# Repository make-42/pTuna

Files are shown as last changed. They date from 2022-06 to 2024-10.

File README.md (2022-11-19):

# pTuna

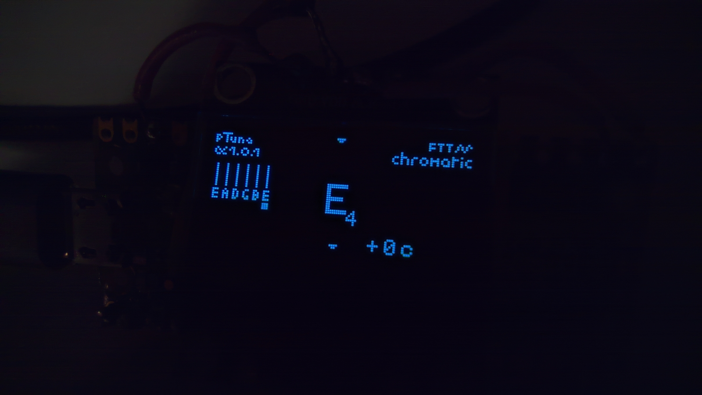
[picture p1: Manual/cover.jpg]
pTuna


An open-source DIY guitar tuner.

## Changelog

```
 - Alpha 1.0.9:
    - New splash screen
    - New boot animation
    - Slightly better code performance
    - Overclocked processor from 125MHz to 150MHz.
    - Version bump: v1.0.1 -> v1.0.9
```

## BOM (Prices in France as of June 2022)

- Raspberry Pi Pico (€ 4)
- SSD1306 OLED Display (€ 1.73)
- Adafruit PDM MEMS Microphone Breakout (Product ID: 3492) (€ 4.62)
- CR2032 (Battery holder) (€ 0.50)
- Toggle switch (€ 0.50)
- Wires (€ 0.40)

Total: € 11.75 (excluding shipping)

Note: If you are in Paris I'd definitely recommend [letmeknow](https://letmeknow.fr) for getting parts. The prices are affordable and the staff lovely!

## Building firmware

- Clone this repo
- Run this command:

`cd ./pTuna/Firmware/final/`

- Edit `build.sh` to point to your pico SDK folder.

- Build with:

`sh build.sh`

## Wiring

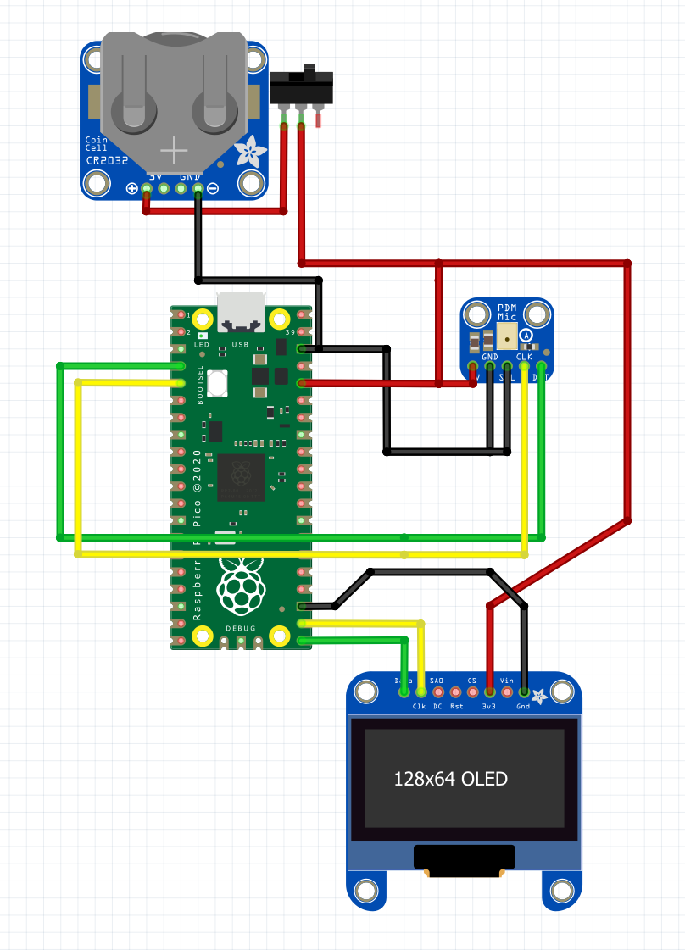
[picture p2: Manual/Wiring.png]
pTuna Wiring


## Schematic

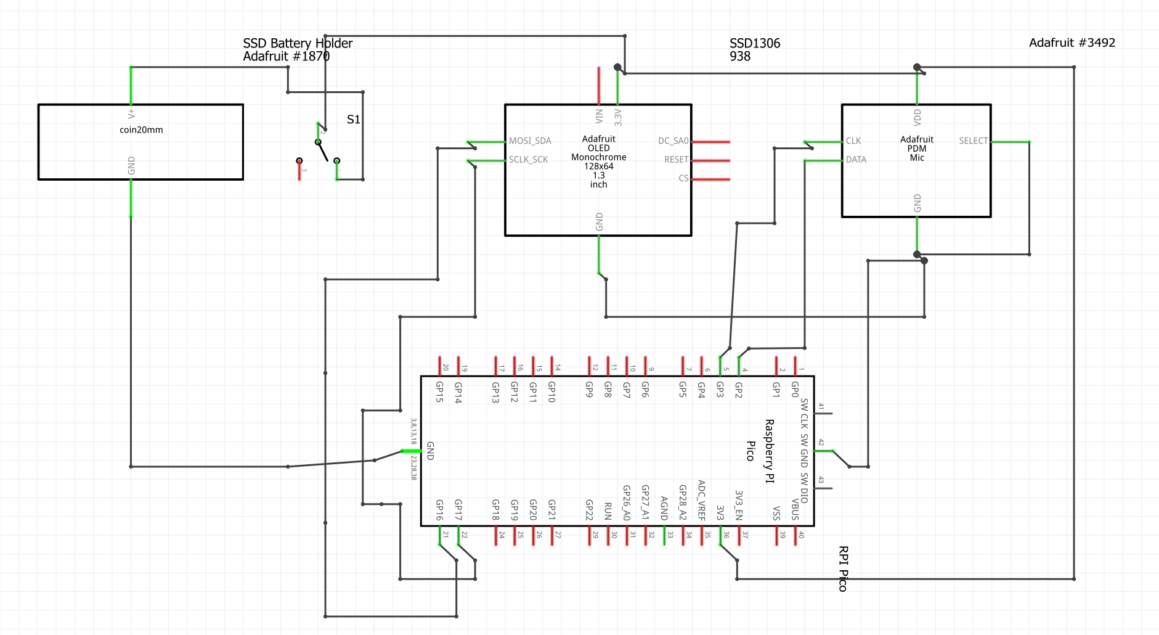
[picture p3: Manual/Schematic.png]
pTuna Schematic


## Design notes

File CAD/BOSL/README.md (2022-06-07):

# BOSL
The Belfry OpenScad Library - A library of tools, shapes, and helpers to make OpenScad easier to use.

This library is a set of useful tools, shapes and manipulators that I developed while working on various
projects, including large ones like the Snappy-Reprap printed 3D printer.

## Installation
1. Download the .zip or .tar.gz release file for this library.
2. Unpack it.  It should create a `BOSL-v1.0` directory with the library files within it.
3. Rename the directory to `BOSL`.
4. Move the `BOSL` directory into the apropriate OpenSCAD library directory for your platform:
    - Windows: `My Documents\OpenSCAD\libraries\`
    - Linux: `$HOME/.local/share/OpenSCAD/libraries/`
    - Mac OS X: `$HOME/Documents/OpenSCAD/libraries/`
5. Restart OpenSCAD.

## Terminology
For purposes of the BOSL library, the following terms apply:
- **Left**: Towards X-
- **Right**: Towards X+
- **Front**/**Forward**: Towards Y-
- **Back**/**Behind**: Towards Y+
- **Bottom**/**Down**/**Below**: Towards Z-
- **Top**/**Up**/**Above**: Towards Z+

- **Axis-Positive**: Towards the positive end of the axis the object is oriented on.  IE: X+, Y+, or Z+.
- **Axis-Negative**: Towards the negative end of the axis the object is oriented on.  IE: X-, Y-, or Z-.

## Common Arguments:

Args    | What it is
------- | ----------------------------------------
fillet  | Radius of rounding for interior or exterior edges.
chamfer | Size of chamfers/bevels for interior or exterior edges.
orient  | Axis a part should be oriented along.  Given as an XYZ triplet of rotation angles.  It is recommended that you use the `ORIENT_` constants from `constants.scad`.  Default is usually `ORIENT_Z` for vertical orientation.
align   | Side of the origin that the part should be on.  Given as a vector away from the origin.  It is recommended that you use the `V_` constants from `constants.scad`.  Default is usually `V_ZERO` for centered.

## Examples
A lot of the features of this library are to allow shorter, easier-to-read, intent-based coding.  For example:

[`BOSL/transforms.scad`](https://github.com/revarbat/BOSL/wiki/transforms.scad) Examples | Raw OpenSCAD Equivalent
------------------------------- | -------------------------------
`up(5)`                         | `translate([0,0,5])`
`xrot(30,cp=[0,10,20])`         | `translate([0,10,20]) rotate([30,0,0]) translate([0,-10,-20])`
`xspread(20,n=3)`               | `for (dx=[-20,0,20]) translate([dx,0,0])`
`zring(n=6,r=20)`               | `for (zr=[0:5]) rotate([0,0,zr*60]) translate([20,0,0])`
`skew_xy(xa=30,ya=45)`          | `multmatrix([[1,0,tan(30),0],[0,1,tan(45),0],[0,0,1,0],[0,0,0,1]])`

[`BOSL/shapes.scad`](https://github.com/revarbat/BOSL/wiki/shapes.scad) Examples | Raw OpenSCAD Equivalent
---------------------------------- | -------------------------------
`upcube([10,20,30]);`              | `translate([0,0,15]) cube([10,20,30], center=true);`
`cuboid([20,20,30], fillet=5, edges=EDGES_Z_ALL);` | `minkowski() {cube([10,10,20], center=true); sphere(r=5, $fn=32);}`
`prismoid([30,40],[20,30],h=10);`  | `hull() {translate([0,0,0.005]) cube([30,40,0.01], center=true); translate([0,0,9.995]) cube([20,30,0.01],center=true);}`
`xcyl(l=20,d=4);`                  | `rotate([0,90,0]) cylinder(h=20, d=4, center=true);`
`cyl(l=100, d=40, fillet=5);`      | `translate([0,0,50]) minkowski() {cylinder(h=90, d=30, center=true); sphere(r=5);}`

[`BOSL/masks.scad`](https://github.com/revarbat/BOSL/wiki/masks.scad) Examples | Raw Openscad Equivalent
----------------------------------- | -------------------------------
`chamfer_mask_z(l=20,chamfer=5);`   | `rotate(45) cube([5*sqrt(2), 5*sqrt(2), 20], center=true);`
`fillet_mask_z(l=20,fillet=5);`     | `difference() {cube([10,10,20], center=true); for(dx=[-5,5],dy=[-5,5]) translate([dx,dy,0]) cylinder(h=20.1, r=5, center=true);}`
`fillet_hole_mask(r=30,fillet=5);`  | `difference() {cube([70,70,10], center=true); translate([0,0,-5]) rotate_extrude(convexity=4) translate([30,0,0]) circle(r=5);}`

## The Library Files
The library files are as follows:

### Commonly Used
  - [`transforms.scad`](https://github.com/revarbat/BOSL/wiki/transforms.scad): The most commonly used transformations, manipulations, and shortcuts are in this file.
  - [`shapes.scad`](https://github.com/revarbat/BOSL/wiki/shapes.scad): Common useful shapes and structured objects.
  - [`masks.scad`](https://github.com/revarbat/BOSL/wiki/masks.scad): Shapes that are useful for masking with `difference()` and `intersect()`.
  - [`threading.scad`](https://github.com/revarbat/BOSL/wiki/threading.scad): Modules to make triangular and trapezoidal threaded rods and nuts.
  - [`paths.scad`](https://github.com/revarbat/BOSL/wiki/paths.scad): Functions and modules to work with arbitrary 3D paths.
  - [`beziers.scad`](https://github.com/revarbat/BOSL/wiki/beziers.scad): Functions and modules to work with bezier curves.

### Standard Parts
  - [`involute_gears.scad`](https://github.com/revarbat/BOSL/wiki/involute_gears.scad): Modules and functions to make involute gears and racks.
  - [`joiners.scad`](https://github.com/revarbat/BOSL/wiki/joiners.scad): Modules to make joiner shapes for connecting separately printed objects.
  - [`sliders.scad`](https://github.com/revarbat/BOSL/wiki/sliders.scad): Modules for creating simple sliders and rails.
  - [`metric_screws.scad`](https://github.com/revarbat/BOSL/wiki/metric_screws.scad): Functions and modules to make metric screws, nuts, and screwholes.
  - [`linear_bearings.scad`](https://github.com/revarbat/BOSL/wiki/linear_bearings.scad): Modules to make mounts for LMxUU style linear bearings.
  - [`nema_steppers.scad`](https://github.com/revarbat/BOSL/wiki/nema_steppers.scad): Modules to make mounting holes for NEMA motors.
  - [`phillips_drive.scad`](https://github.com/revarbat/BOSL/wiki/phillips_drive.scad): Modules to create Phillips screwdriver tips.
  - [`torx_drive.scad`](https://github.com/revarbat/BOSL/wiki/torx_drive.scad): Functions and Modules to create Torx bit drive holes.
  - [`wiring.scad`](https://github.com/revarbat/BOSL/wiki/wiring.scad): Modules to render routed bundles of wires.

### Miscellaneous
  - [`math.scad`](https://github.com/revarbat/BOSL/wiki/math.scad): Useful helper functions.
  - [`constants.scad`](https://github.com/revarbat/BOSL/wiki/constants.scad): Useful constants for vectors, edges, etc.
  - [`quaternions.scad`](https://github.com/revarbat/BOSL/wiki/quaternions.scad): Functions to work with quaternion rotations.
  - [`debug.scad`](https://github.com/revarbat/BOSL/wiki/debug.scad): Modules to help debug creation of beziers, `polygons()`s and `polyhedron()`s

## Documentation
The full library docs can be found at https://github.com/revarbat/BOSL/wiki

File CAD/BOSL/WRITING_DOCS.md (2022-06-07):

# Formatting Comments for Docs

Documentation and example images are generated automatically from source code comments by the `scripts/docs_gen.py` script.  Not all comments are added to the wiki.  Just those comment blocks starting with certain keywords:

- `// LibFile: NAME`
- `// Section: NAME`
- `// Module: NAME`
- `// Function: NAME`
- `// Constant: NAME`

## LibFile:

LibFile blocks can be followed by multiple lines that can be added as markdown text after the header. Indentation is important, as it denotes the end of block.

```
// LibFile: foo.scad
//   You can have several lines of markdown formatted text here.
//   You just need to make sure that each line is indented, with
//   at least three spaces after the comment marker.  You can
//   denote a paragraph break with a comment line with three
//   trailing spaces.
//   
//   The end of the block is denoted by a line without a comment.
```

## Section:

Section blocks can be followed by multiple lines that can be added as markdown text after the header. Indentation is important, as it denotes the end of block.

Sections can also include Figures; images generated from code that is not shown in a code block.

```
// Section: Foobar
//   You can have several lines of markdown formatted text here.
//   You just need to make sure that each line is indented with
//   at least three spaces after the comment marker.  You can
//   denote a paragraph break with a comment line with three
//   trailing spaces.
//   
//   The end of the block is denoted by a line without a comment,
//   or a line that is unindented after the comment.
// Figure: Figure description
//   cylinder(h=100, d1=75, d2=50);
//   up(100) cylinder(h=100, d1=50, d2=75);
// Figure(Spin): Animated figure that spins to show all faces.
//   cube([10,100,50], center=true);
//   cube([100,10,30], center=true);
```

## CommonCode:

CommonCode blocks can be used to denote code that can be shared between all of the Figure and Example blocks in the file, without being shown itself.  Indentation is important.  Less than three spaces indent denotes the end of the block

```
// CommonCode:
//   module text3d(text, h=0.01, size=3) {
//       linear_extrude(height=h, convexity=10) {
//           text(text=text, size=size, valign="center", halign="center");
//       }
//   }
```

## Module:/Function:/Constant:

Module, Function, and Constant docs blocks all have a similar specific format.  Most sub-blocks are optional, except the Module/Function/Constant line, and the Description block.

Valid sub-blocks are:

- `Status: DEPRECATED, use blah instead.` - Optional, used to denote deprecation.
- `Usage: Optional Usage Title` - Optional.  Multiple allowed.  Followed by an indented block of usage patterns.  Optional arguments should be in braces like `[opt]`.  Alternate args should be separated by a vertical bar like `r|d`. 
- `Description:` - Can be single-line or a multi-line block of the description.
- `Arguments:` - Denotes start of an indented block of argument descriptions.  Each line has the argument name, a space, an equals, another space, then the description for the argument all on one line. Like `arg = The argument description`.  If you really need to explain an argument in longer form, explain it in the Description.
- `Side Effects:` - Denotes the start of a block describing the side effects, such as `$special_var`s that are set.
- `Example:` - Denotes the beginning of a multi-line example code block.
- `Examples:` - Denotes the beginning of a block of examples, where each line will be shows as a separate example with a separate image if needed.

Modules blocks will generate images for each example block. Function and Constant blocks will only generate images for example blocks if they have `2D` or `3D` tags.  Example blocks can have tags added by putting then inside parentheses before the colon.  Ie: `Examples(BigFlatSpin):`.  

The full set of optional example tags are:

- `2D`: Orient camera in a top-down view for showing 2D objects.
- `3D`: Orient camera in an oblique view for showing 3D objects. Used to force an Example sub-block to generate an image in Function and Constant blocks.
- `Spin`: Animate camera orbit around the `[0,1,1]` axis to display all sides of an object.
- `FlatSpin` : Animate camera orbit around the Z axis, above the XY plane.
- `FR`: Force full rendering from OpenSCAD, instead of the normal preview.
- `Small`: Make the image small sized.
- `Med`: Make the image medium sized.
- `Big`: Make the image big sized.

Indentation is important, as it denotes the end of sub-block.

```
// Module: foo()
// Status: DEPRECATED, use BLAH instead.
// Usage: Optional Usage Description
//   foo(foo, bar, [qux]);
//   foo(bar, baz, [qux]);
// Usage: Another Optional Usage Description
//   foo(foo, flee, flie, [qux])
// Description: Short description.
// Description:
//   A longer, multi-line description.
//   All description blocks are added together.
//   You _can_ use *markdown* notation as well.
//   You can end multi-line blocks by un-indenting the
//   next line, or by using a blank comment line like this:
//
// Arguments:
//   foo = This is the description of the foo argument.  All on one line.
//   bar = This is the description of the bar argument.  All on one line.
//   baz = This is the description of the baz argument.  All on one line.
//   qux = This is the description of the qux argument.  All on one line.
//   flee = This is the description of the flee argument.  All on one line.
//   flie = This is the description of the flie argument.  All on one line.
// Side Effects:
//   `$floo` gets set to the floo value.
// Examples: Each line below gets its own example block and image.
//   foo(foo="a", bar="b");
//   foo(foo="b", baz="c");
// Example: Multi-line example.
//   lst = [
//       "multi-line examples",
//       "are shown in one block",
//       "with a single image.",
//   ];
//   foo(lst, 23, "blah");
// Example(2D): Example to show as 2D top-down rendering.
//   foo(foo="b", baz="c", qux=true);
// Example(Spin): Example orbiting the [0,1,1] axis.
//   foo(foo="b", baz="c", qux="full");
// Example(FlatSpin): Example orbiting the Z axis from above.
//   foo(foo="b", baz="c", qux="full2");
```

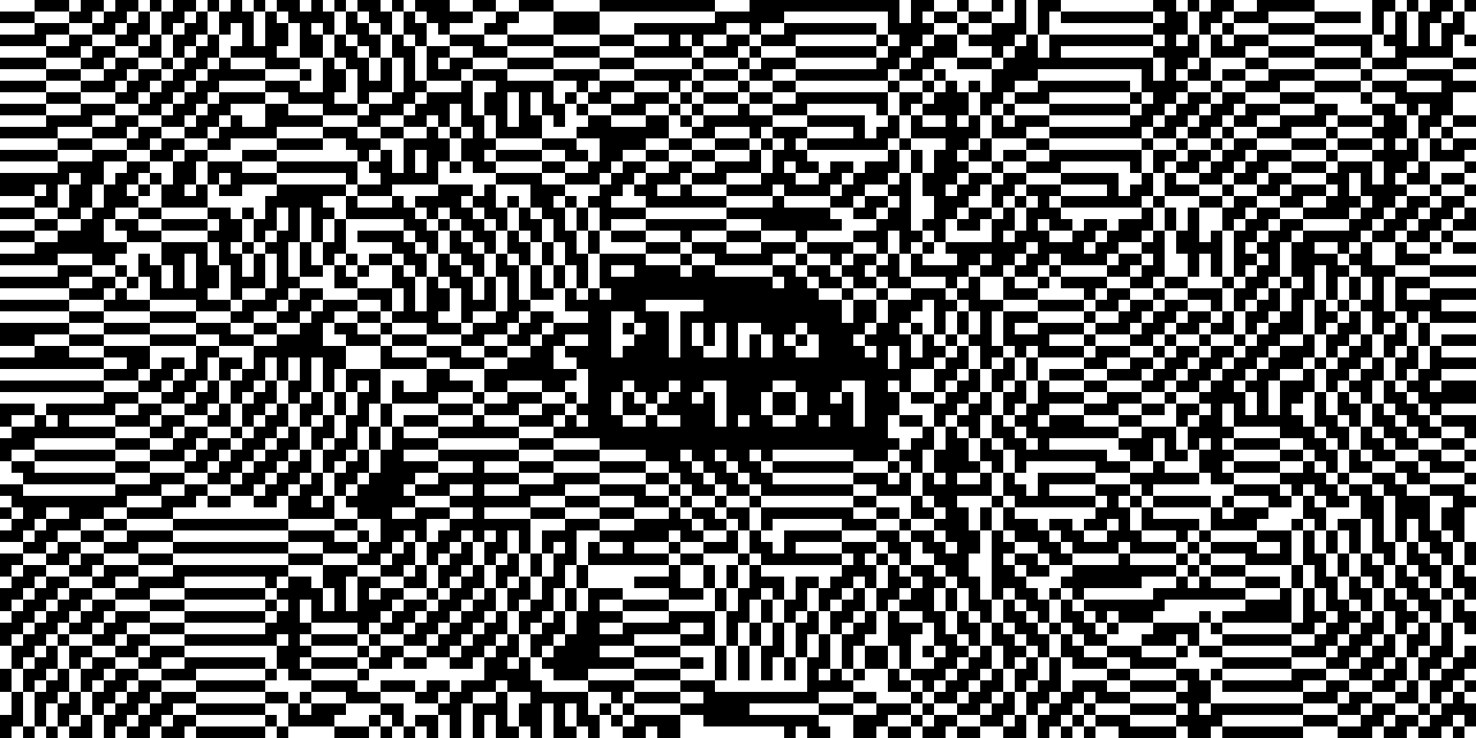
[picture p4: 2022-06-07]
Firmware/final/assets/dotpict_20220529_085223.png

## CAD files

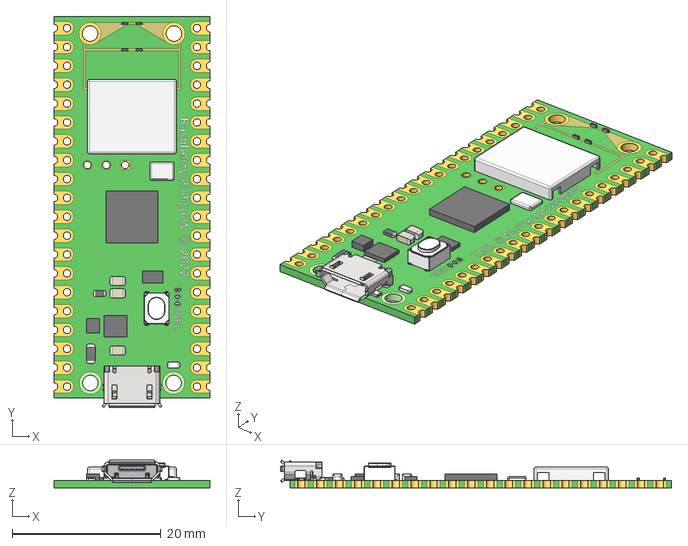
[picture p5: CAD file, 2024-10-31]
CAD/Drawing Assets/RaspberryPi-PicoW-NoPins.step
21.0 x 52.7 x 3.71 mm

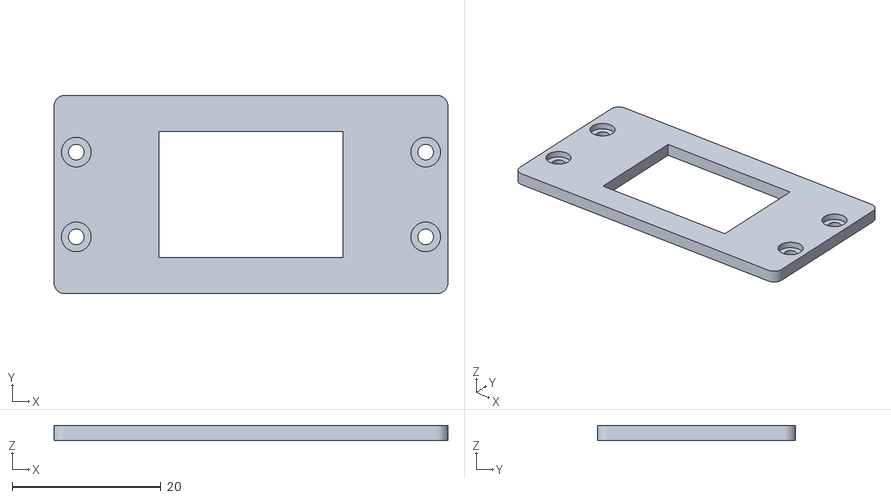
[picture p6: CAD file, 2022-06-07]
CAD/top.stl
53.0 x 26.7 x 2.00

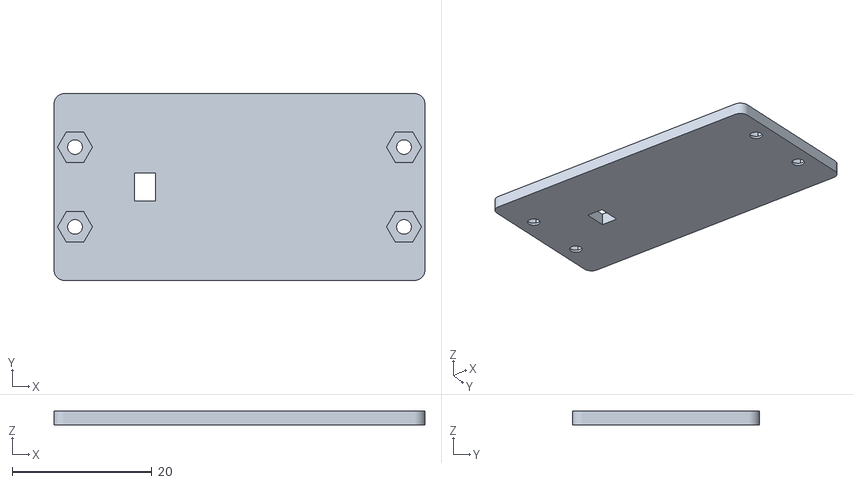
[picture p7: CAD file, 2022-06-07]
CAD/bottom.stl
53.0 x 26.7 x 2.00

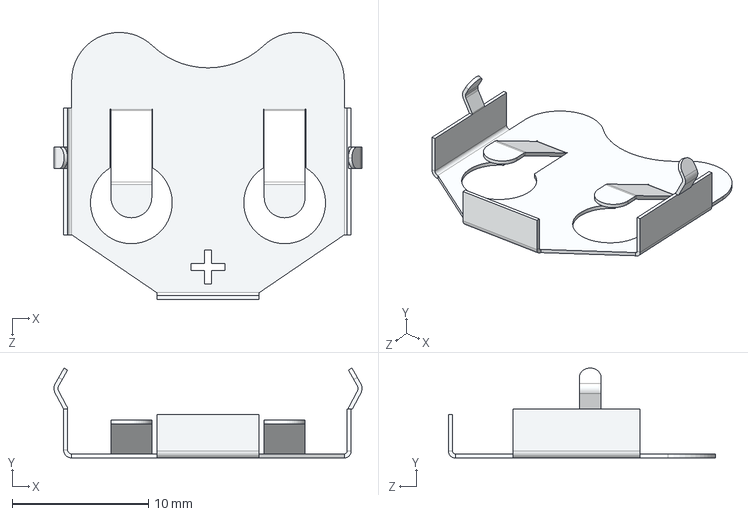
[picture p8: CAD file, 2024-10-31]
CAD/Drawing Assets/CLIP_CR2032_RS_PRO_2378331.step
22.6 x 6.60 x 19.6 mm

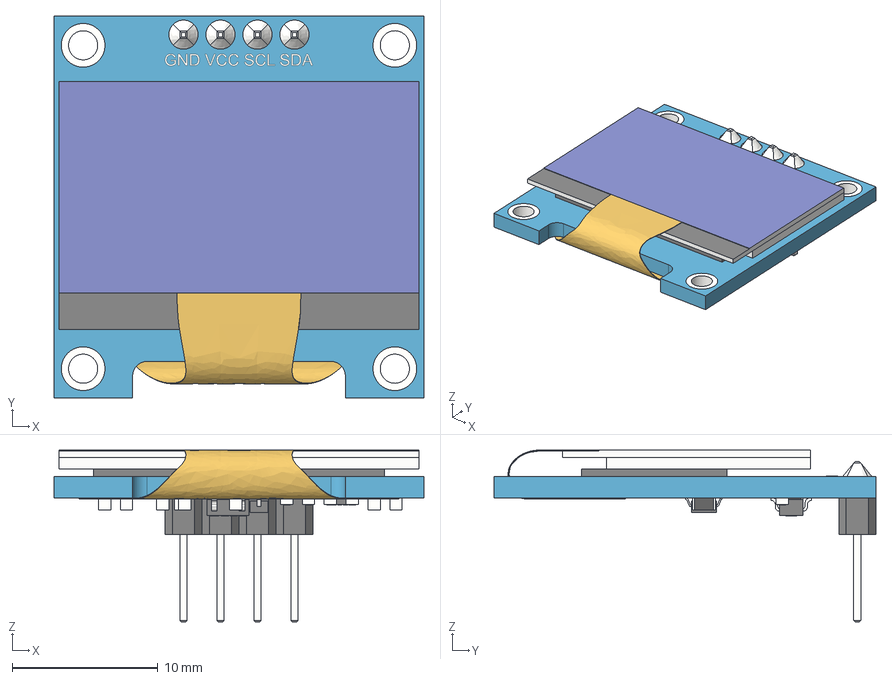
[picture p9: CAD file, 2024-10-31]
CAD/Drawing Assets/SSD1306_OLED_Display(128x64).step
25.4 x 26.2 x 11.8 mm
board
screen
pin_header
soldering
smd_capacitor
smd_capacitor (1)
914_smd_resistor
472_smd_resistor x 3
t4_smd_diode
smd_capacitor (2)
smd_capacitor (3)
smd_capacitor (4)
smd_capacitor (5)
smd_capacitor (6)
472_smd_resistor (1)
SOT-23_XC6206 v3
smd_capacitor (7)
flat_cable

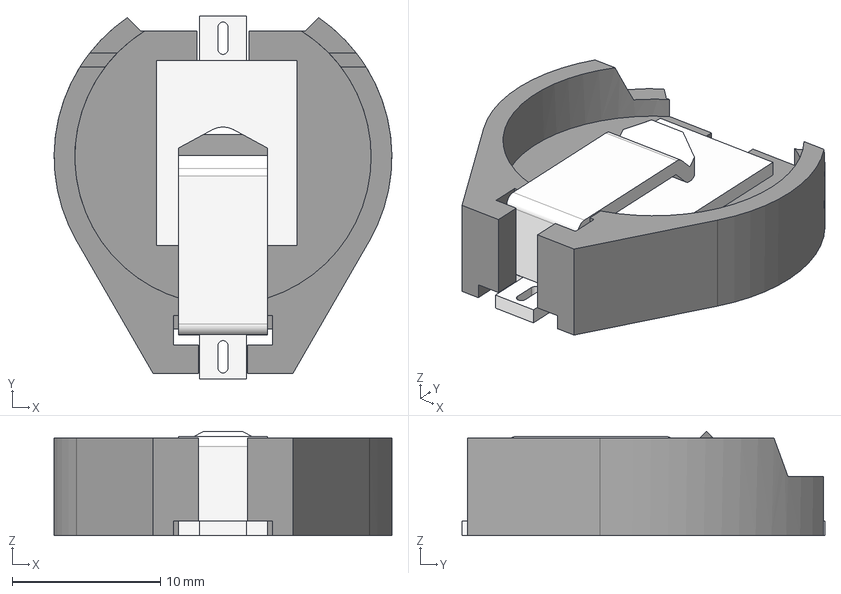
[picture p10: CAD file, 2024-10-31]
CAD/Drawing Assets/keystone_1061.step
22.8 x 24.5 x 7.03 mm
Negative_plate
Positive_plate

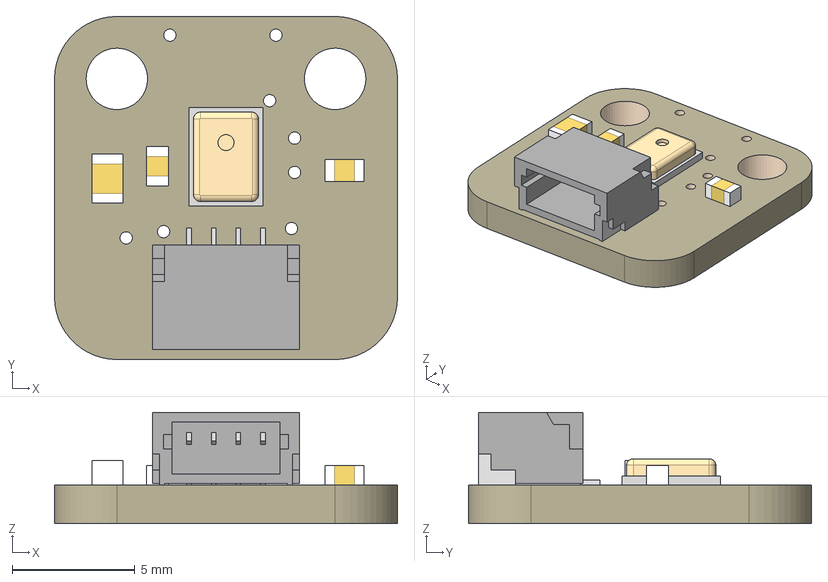
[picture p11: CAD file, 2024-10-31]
CAD/Drawing Assets/PDM Mic with JST SH.step
14.0 x 14.0 x 4.53 mm
Board
10K x 2
10uF
MIC_PDM_SPK0415
STEMMA_I2C_QT

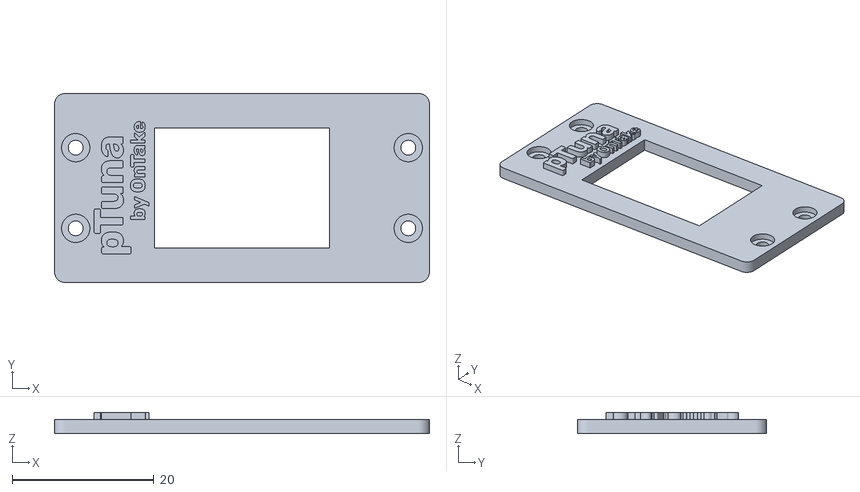
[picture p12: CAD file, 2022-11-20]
CAD/Drawing Assets/top-v2.stl
53.0 x 26.7 x 3.00

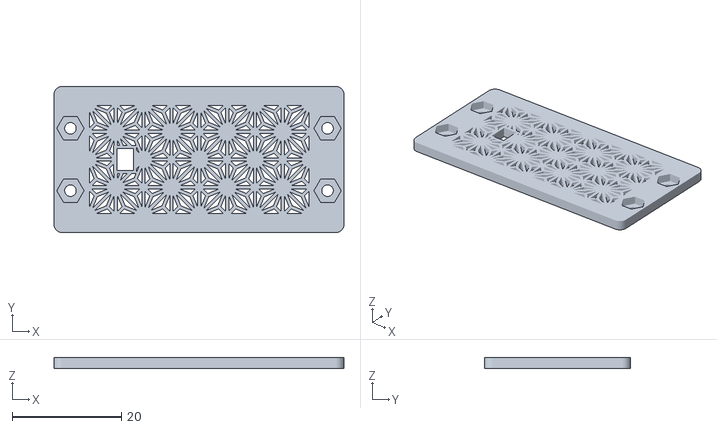
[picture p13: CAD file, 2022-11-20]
CAD/Drawing Assets/bottom-v2.stl
53.0 x 26.7 x 2.00

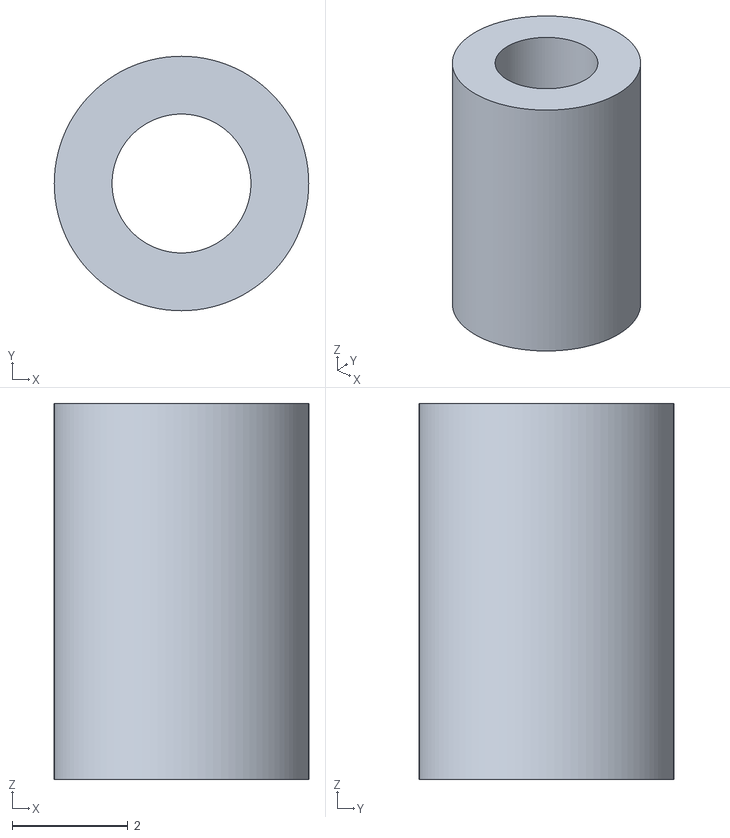
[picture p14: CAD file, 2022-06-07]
CAD/Drawing Assets/standoffs.stl
4.40 x 4.40 x 6.50

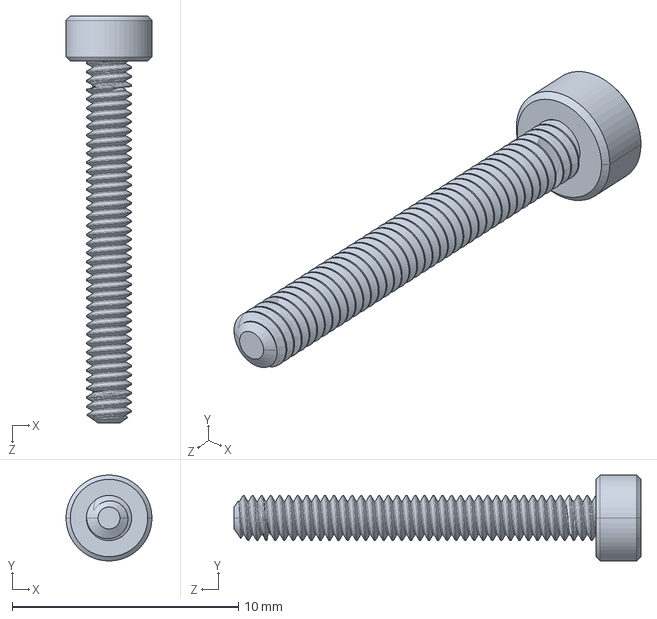
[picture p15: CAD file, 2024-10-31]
CAD/Drawing Assets/M2 x 0.4mm Thread 16mm LONG SOCKET HEAD CAP SCREW.STEP
3.80 x 3.80 x 18.0 mm

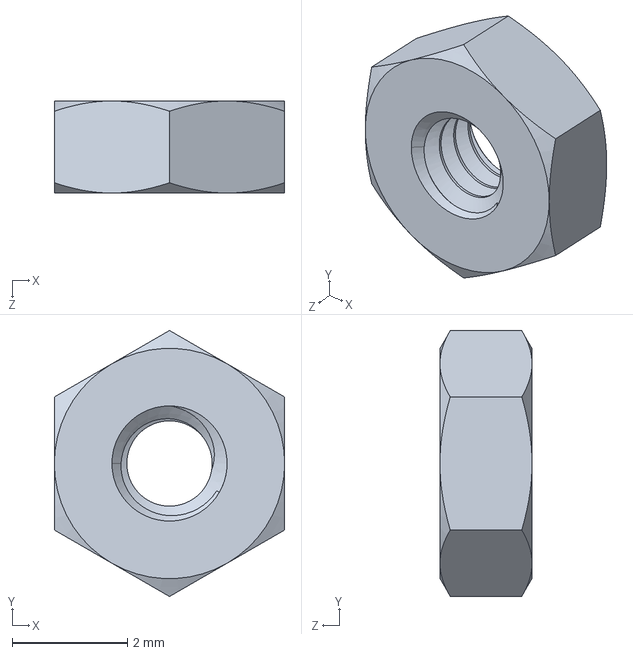
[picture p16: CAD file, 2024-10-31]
CAD/Drawing Assets/M2 x 0.4mm Thread HEX NUT.STEP
4.00 x 4.62 x 1.60 mm

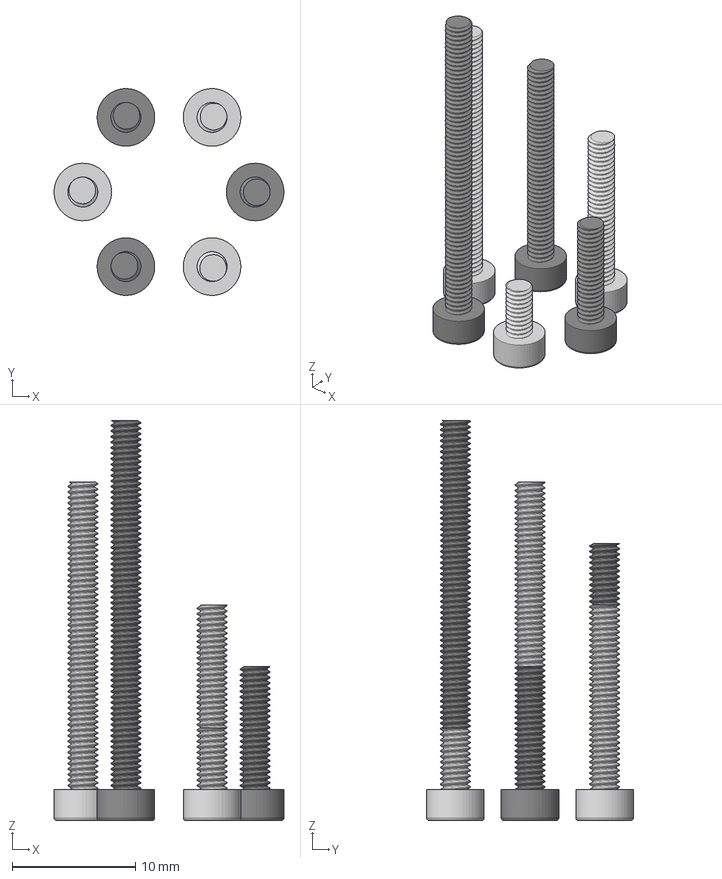
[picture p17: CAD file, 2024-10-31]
CAD/Drawing Assets/M2.5 Hex Screw v2.step
18.7 x 16.8 x 32.5 mm

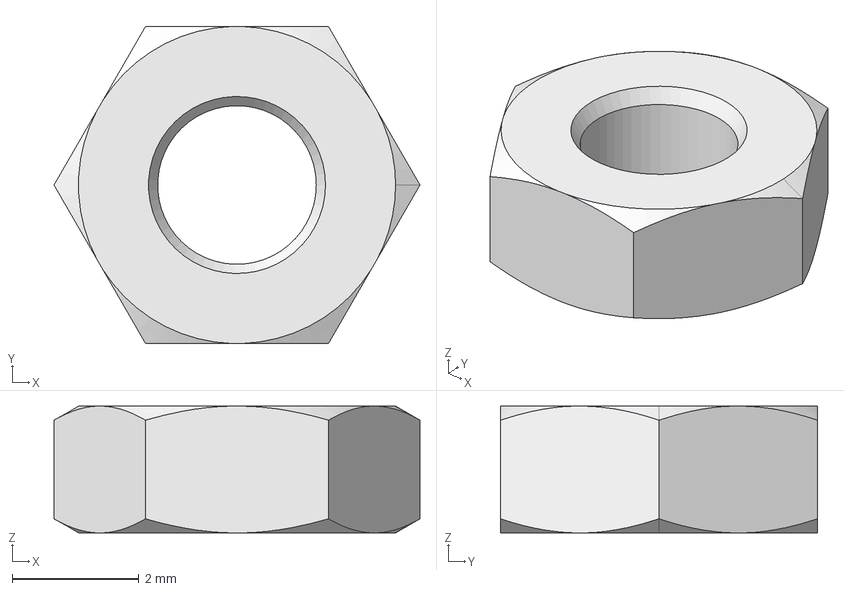
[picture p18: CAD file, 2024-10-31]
CAD/Drawing Assets/hexagonal_nut_normal_height_M2.5.step
5.77 x 5.00 x 2.00 mm

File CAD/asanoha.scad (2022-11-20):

patternScale = 5.0875;
patternThickness = 0.6;
patternDepth = 2;
repeatX = 4;
repeatY = 2;

module drawLine(a=0,b=0,xStart=0,xEnd=0)
{ 
    lineLength = sqrt(pow(a*(xEnd-xStart),2)+pow(xEnd-xStart,2))+patternThickness;
    translate([xStart,a*xStart+b,0])
    rotate([0,0,atan(a)]) translate ([-patternThickness/2,-patternThickness/2,-patternDepth/2]) cube([lineLength,patternThickness,patternDepth]);  
}

module drawYLine(xOrig=0,yOrig=0,length=0)
{ 
    lineLength = length+patternThickness;
    translate([xOrig,yOrig,0])
    rotate([0,0,90]) translate ([-patternThickness/2,-patternThickness/2,-patternDepth/2]) cube([lineLength,patternThickness,patternDepth]);  
}


module asanoha(){

    interXT = patternScale/(1+tan(67.5));

    drawLine(0,0,0,patternScale);
    drawLine(-1,0,0,interXT);
    drawLine(tan(67.5),-patternScale,0,interXT);
    drawLine(tan(22.5),-patternScale*tan(22.5),interXT,patternScale);
    
    
    interXB = patternScale/(1+tan(22.5));
    
    drawLine(0,-patternScale,0,patternScale);
    drawLine(-1,0,interXB,patternScale);
    drawLine(tan(22.5),-patternScale,0,interXB);
    drawLine(tan(67.5),-patternScale*tan(67.5),interXB,patternScale);
    
    
    drawLine(1,-patternScale,0,patternScale);
    drawYLine(0,-patternScale,patternScale);
    drawYLine(patternScale,-patternScale,patternScale);
}

module movePattern(repeatXN=0,repeatYN=0){
    translate([patternScale*2*repeatXN,patternScale*2*repeatYN,0]) children();
}

module fullAsanoha(){
    asanoha();
    rotate([0,0,90]) translate([-patternScale,-patternScale,0]) asanoha();
    rotate([0,0,90]) asanoha();
    translate([patternScale,patternScale,0]) asanoha();
}

module drawAsanoha(){
    translate([0,patternScale,patternDepth/2])
// Actually start drawing things
for(repeatXN = [0 : repeatX-1]){
    for(repeatYN = [0 : repeatY-1]){
        movePattern(repeatXN,repeatYN) fullAsanoha();
    }
}

}

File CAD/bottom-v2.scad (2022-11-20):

include <BOSL/constants.scad>
include <asanoha.scad>
use <BOSL/masks.scad>

// Start config
// Pi Board
pi_board_size = [51,21]; //mm
pi_board_screw_holes_center_from_board_edge_distance = [3.7/2/*3.7 is the difference between screen and pi pcb height 21-24.7 */+4.8,2]; //mm
pi_board_screw_holes_diameter = 2.1; //mm
pi_board_padding = 1; //mm

// Screen
screen_pcb_size = [24.7,27,13.3]; //mm (+- 0.2) 13.3mm are pin headers.
screen_pcb_screw_holes_center_from_board_edge_distance = 2.1; //mm
screen_pcb_screw_holes_diameter=2.8; //mm
screen_pcb_screw_holes_spacing=[20.5,23]; //mm
active_screen_area = [24.7,16.9,3.5]; //mm (old: 13.86)
active_screen_area_offset_from_corner = [0,5.08]; //mm

// MEMS Package (HCLGA)
mems_microphone_package_size = [3,4,1.06]; //mm https://cdn-learn.adafruit.com/assets/assets/000/049/977/original/MP34DT01-M.pdf
mems_microphone_position_offset_from_corner = [11.5,pi_board_padding+screen_pcb_size.x/2-mems_microphone_package_size.y/2,0]; //mm
mems_border_size = 0.6; // mm

// Asanoha pattern
asanoha_pattern_size = [40.7,20.35,1]; //mm 
asanoha_pattern_offset_from_corner = [(pi_board_padding+pi_board_screw_holes_diameter)*2,pi_board_padding+screen_pcb_size.x/2-asanoha_pattern_size.y/2,mems_microphone_position_offset_from_corner.z]; //mm


// Screws
m2_screw_nut_size = [5,5,1.6];

// Misc
walls_thickness = 2; //mm
rounding_radius=1.5; //mm

resolution = 80;
// End config

// Modules
module sector(radius, angles, fn = resolution) {
    r = radius / cos(180 / fn);
    step = -360 / fn;

    points = concat([[0, 0]],
        [for(a = [angles[0] : step : angles[1] - 360]) 
            [r * cos(a), r * sin(a)]
        ],
        [[r * cos(angles[1]), r * sin(angles[1])]]
    );

    difference() {
        circle(radius, $fn = fn);
        polygon(points);
    }
}

module arc(radius, angles, width = 1, fn = resolution) {
    difference() {
        sector(radius + width, angles, fn);
        sector(radius, angles, fn);
    }
}

// Modeling
difference(){
// Body
cube(size=[pi_board_size.x+2*pi_board_padding,screen_pcb_size.x+2*pi_board_padding,walls_thickness]);
   // Fillet Edge
    fillet_mask_z(l=walls_thickness, r=rounding_radius, align=V_UP, $fn=resolution);
    
   translate([pi_board_size.x+2*pi_board_padding,screen_pcb_size.x+2*pi_board_padding,0])
    fillet_mask_z(l=walls_thickness, r=rounding_radius, align=V_UP, $fn=resolution);
    
   translate([pi_board_size.x+2*pi_board_padding,0,0]) fillet_mask_z(l=walls_thickness, r=rounding_radius, align=V_UP, $fn=resolution);
    
   translate([0,screen_pcb_size.x+2*pi_board_padding,0]) fillet_mask_z(l=walls_thickness, r=rounding_radius, align=V_UP, $fn=resolution);
    // MEMS Package (HCLGA)
    translate(mems_microphone_position_offset_from_corner) cube(size=[mems_microphone_package_size.x,mems_microphone_package_size.y,walls_thickness]);
    // Screws + Nuts
    translate([pi_board_screw_holes_center_from_board_edge_distance.y+pi_board_padding,pi_board_screw_holes_center_from_board_edge_distance.x+pi_board_padding,0]) cylinder(walls_thickness,pi_board_screw_holes_diameter/2,pi_board_screw_holes_diameter/2,$fn=resolution);
    
    translate([pi_board_screw_holes_center_from_board_edge_distance.y+pi_board_padding,pi_board_screw_holes_center_from_board_edge_distance.x+pi_board_padding,walls_thickness-m2_screw_nut_size.z]) cylinder(m2_screw_nut_size.z,m2_screw_nut_size.x/2,m2_screw_nut_size.x/2,$fn=6);
    
    translate([pi_board_screw_holes_center_from_board_edge_distance.y+pi_board_padding,screen_pcb_size.x-pi_board_screw_holes_center_from_board_edge_distance.x+pi_board_padding,0]) cylinder(walls_thickness,pi_board_screw_holes_diameter/2,pi_board_screw_holes_diameter/2,$fn=resolution);
    
    translate([pi_board_screw_holes_center_from_board_edge_distance.y+pi_board_padding,screen_pcb_size.x-pi_board_screw_holes_center_from_board_edge_distance.x+pi_board_padding,walls_thickness-m2_screw_nut_size.z]) cylinder(m2_screw_nut_size.z,m2_screw_nut_size.x/2,m2_screw_nut_size.x/2,$fn=6);
    
    translate([pi_board_size.x-pi_board_screw_holes_center_from_board_edge_distance.y+pi_board_padding,pi_board_screw_holes_center_from_board_edge_distance.x+pi_board_padding,0]) cylinder(walls_thickness,pi_board_screw_holes_diameter/2,pi_board_screw_holes_diameter/2,$fn=resolution);
    
    translate([pi_board_size.x-pi_board_screw_holes_center_from_board_edge_distance.y+pi_board_padding,pi_board_screw_holes_center_from_board_edge_distance.x+pi_board_padding,walls_thickness-m2_screw_nut_size.z]) cylinder(m2_screw_nut_size.z,m2_screw_nut_size.x/2,m2_screw_nut_size.x/2,$fn=6);
    
    translate([pi_board_size.x-pi_board_screw_holes_center_from_board_edge_distance.y+pi_board_padding,screen_pcb_size.x-pi_board_screw_holes_center_from_board_edge_distance.x+pi_board_padding,0]) cylinder(walls_thickness,pi_board_screw_holes_diameter/2,pi_board_screw_holes_diameter/2,$fn=resolution);
    
    translate([pi_board_size.x-pi_board_screw_holes_center_from_board_edge_distance.y+pi_board_padding,screen_pcb_size.x-pi_board_screw_holes_center_from_board_edge_distance.x+pi_board_padding,walls_thickness-m2_screw_nut_size.z]) cylinder(m2_screw_nut_size.z,m2_screw_nut_size.x/2,m2_screw_nut_size.x/2,$fn=6);
    
    translate(asanoha_pattern_offset_from_corner) cube(size=[asanoha_pattern_size.x,asanoha_pattern_size.y,walls_thickness]);

}

difference(){
    union(){
        // MEMS Package (HCLGA)
    translate(asanoha_pattern_offset_from_corner) drawAsanoha();
    translate([mems_microphone_position_offset_from_corner.x-
mems_border_size,mems_microphone_position_offset_from_corner.y-
mems_border_size,mems_microphone_position_offset_from_corner.z]) cube(size=[mems_microphone_package_size.x+mems_border_size*2,mems_microphone_package_size.y+mems_border_size*2,walls_thickness]);
    }
    // MEMS Package (HCLGA)
    translate(mems_microphone_position_offset_from_corner) cube(size=[mems_microphone_package_size.x,mems_microphone_package_size.y,walls_thickness]);
    
    
}

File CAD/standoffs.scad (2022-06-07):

// Start config

// Standoffs
length = 6.5; //mm
diameter = 2+0.4; //mm (m2 + 0.4mm clearance)
wall_thickness = 1;//mm
// Misc
resolution = 100;
// End config

// Modeling
difference(){
    cylinder(length,diameter/2+wall_thickness,diameter/2+wall_thickness,$fn=resolution);
    cylinder(length,diameter/2,diameter/2,$fn=resolution);
   }

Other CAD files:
CAD/top-v2.scad
CAD/BOSL/acme_screws.scad
CAD/BOSL/beziers.scad
CAD/BOSL/compat.scad
CAD/BOSL/constants.scad
CAD/BOSL/convex_hull.scad
CAD/BOSL/debug.scad
CAD/BOSL/examples/bezier_patches.scad
CAD/BOSL/examples/orientations.scad
CAD/BOSL/involute_gears.scad
CAD/BOSL/joiners.scad
CAD/BOSL/linear_bearings.scad
CAD/BOSL/masks.scad
CAD/BOSL/math.scad
CAD/BOSL/metric_screws.scad
CAD/BOSL/nema_steppers.scad
CAD/BOSL/paths.scad
CAD/BOSL/phillips_drive.scad
CAD/BOSL/quaternions.scad
CAD/BOSL/shapes.scad
CAD/BOSL/sliders.scad
CAD/BOSL/tests/test_convex_hull.scad
CAD/BOSL/tests/test_math.scad
CAD/BOSL/threading.scad
CAD/BOSL/torx_drive.scad
CAD/BOSL/transforms.scad
CAD/BOSL/triangulation.scad
CAD/BOSL/wiring.scad
CAD/Drawing Assets/PDM Mic with JST SH.f3d
CAD/Drawing Assets/SSD1306_OLED_Display(128x64).f3d
CAD/bottom.scad
CAD/top.scad
Firmware/final/assets/final/blend/2.blend

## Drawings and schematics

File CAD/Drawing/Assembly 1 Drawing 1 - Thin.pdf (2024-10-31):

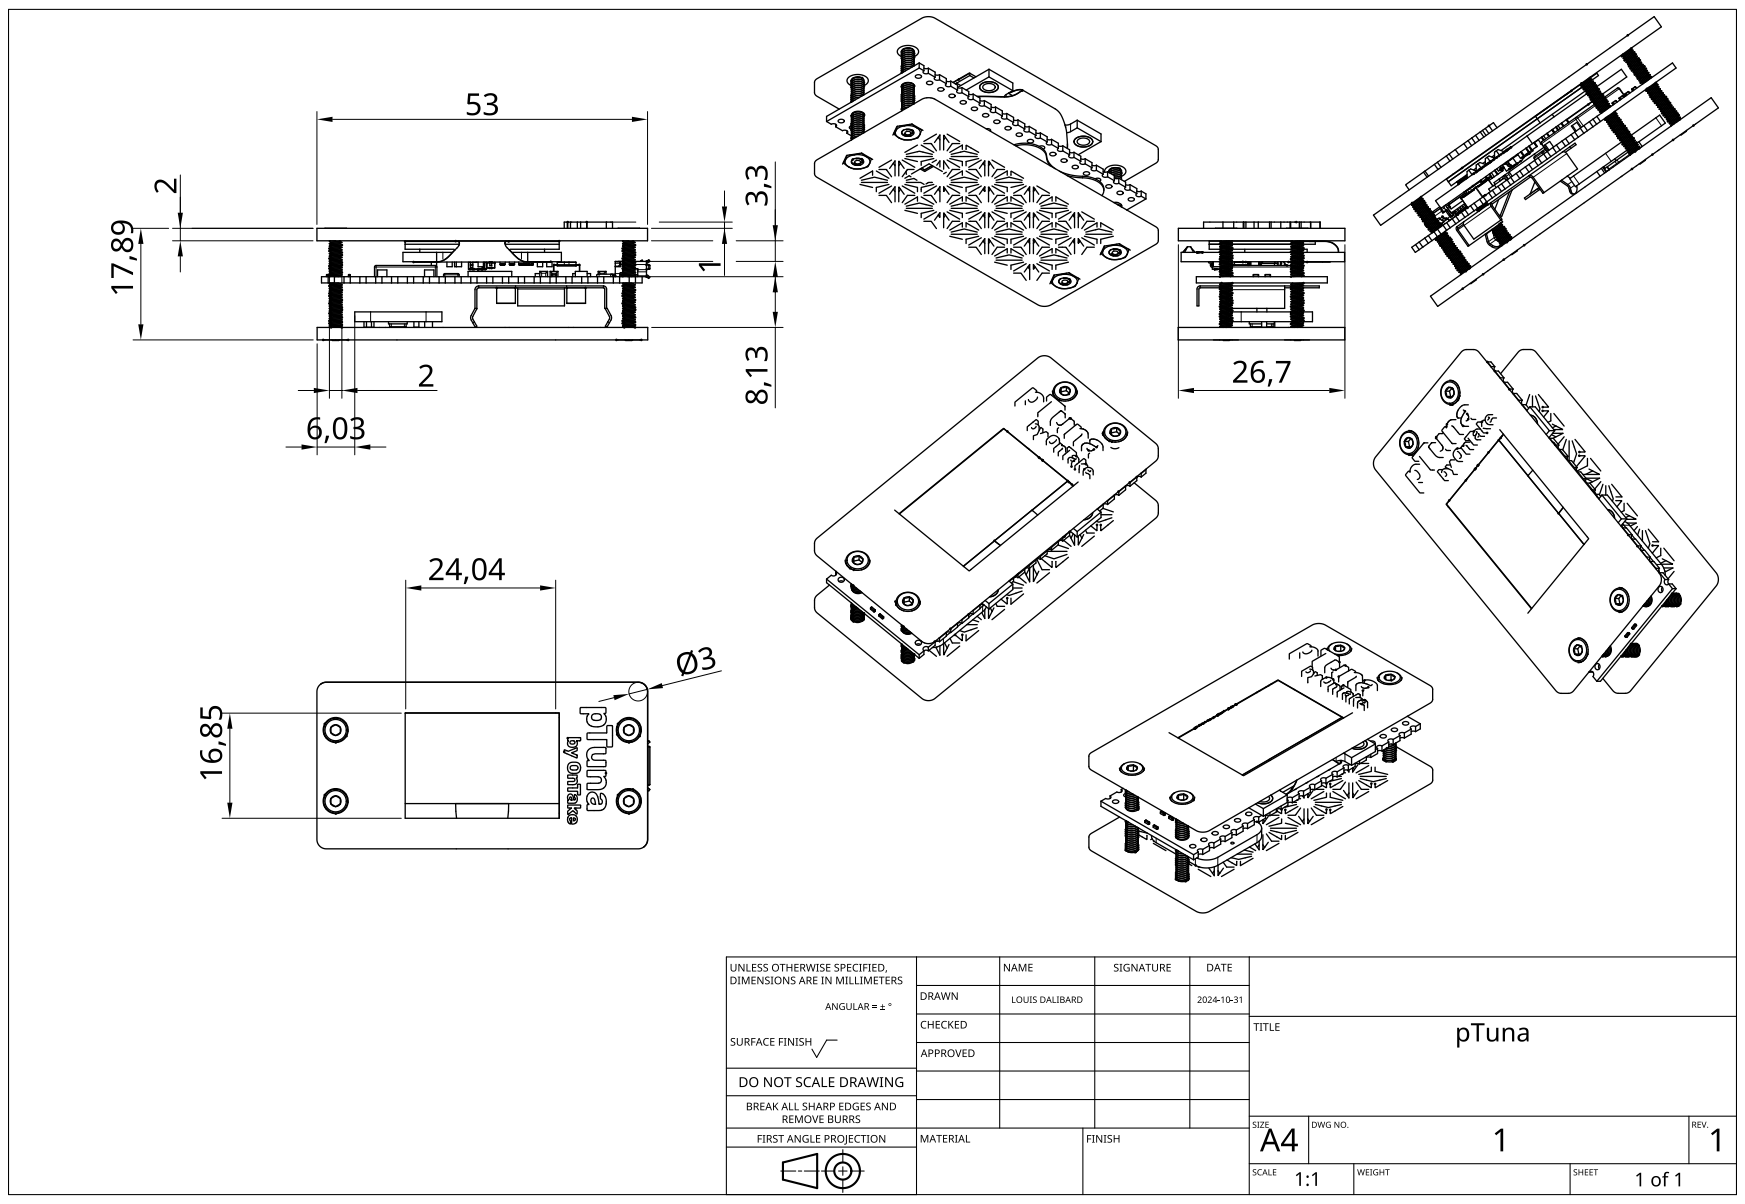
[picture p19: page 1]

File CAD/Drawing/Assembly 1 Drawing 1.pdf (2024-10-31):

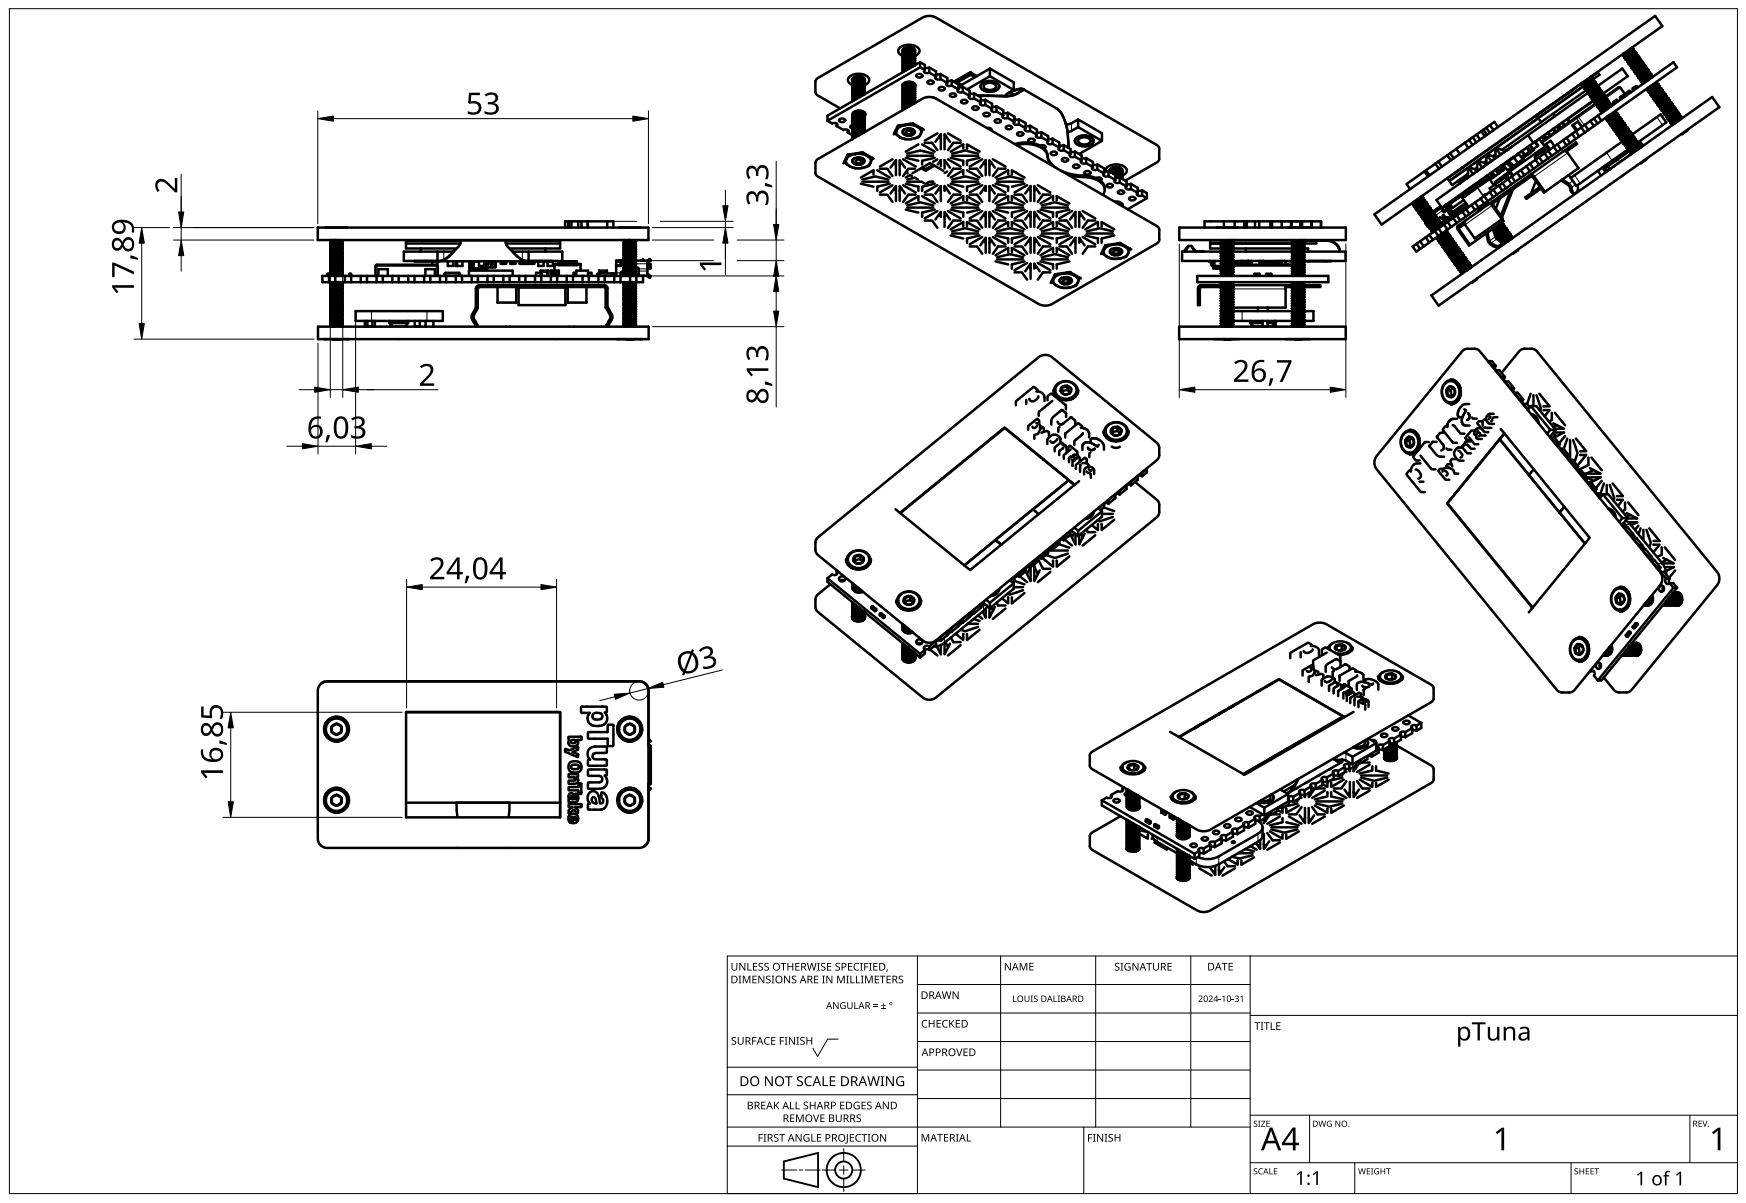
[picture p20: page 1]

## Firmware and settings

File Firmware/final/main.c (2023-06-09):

/////////////////////////////////////////////////////////////////////////////////////////
// Filename:    main.c
// Filetype:    javascript
// Author:      Louis Dalibard
// Created On:  May 29th 2022 @ 11:18PM
// Description: pTuna : α 1.01
/////////////////////////////////////////////////////////////////////////////////////////

#include <stdio.h>
#include <stdint.h>
#include <string.h>
#include <stdlib.h>
#include <math.h>

#include "pico/stdlib.h"
#include "pico/pdm_microphone.h"
#include "pico/multicore.h"
#include "hardware/i2c.h"

#include "libssd1306/ssd1306.h"

#include "bitmaps/splashScreen.h"
#include "bitmaps/mainUI.h"
#include "bitmaps/overclockFail.h"

#include "notes/notes.h"

#include "kiss/kiss_fftr.h"

#define SPLASHSCREEN_DURATION 1200 //ms
#define C0_FREQUENCY 16.3515978313 //hz C8(4186.01hz) / 4186.01/(2^8) (440/(2^(9/12+4)) would be more exact though)
#define CUTOFF_FREQUENCY 8.17580078125 //hz
#define SEMITONE_OFFSET_SENSITIVITY 1.24 // cents per pixel (64-2)/50
#define MIC_BUFFER_SIZE 512 // samples
#define CUMUL_BUFFER_SIZE 8 // multiplier, int
#define MIC_SAMPLERATE 4096 // hz
#define MIC_GAIN 1.0 // multiplier
#define BOOT_ANIMATION_FRAMES 60
#define SHOW_BOOT_ANIMATION false

#define OSCILLOSCOPE_SAMPLES 50
#define OSCILLOSCOPE_GAIN 15

#define FLAG_VALUE 123

// configuration
const struct pdm_microphone_config config = {
  .gpio_data = 2,
  .gpio_clk = 3,
  .pio = pio0,
  .pio_sm = 0,
  .sample_rate = MIC_SAMPLERATE,
  .sample_buffer_size = MIC_BUFFER_SIZE,
};

// variables
int16_t sample_buffer[MIC_BUFFER_SIZE];
int16_t sample_buffer_cumul[MIC_BUFFER_SIZE*CUMUL_BUFFER_SIZE];
volatile int samples_read = 0;
float freqs[MIC_BUFFER_SIZE*CUMUL_BUFFER_SIZE];

// functions
void setup_gpios(void);
void setup_microphone(void);
void splashscreen(ssd1306_t disp);
void overclockFail(ssd1306_t disp);
void showMainUI(ssd1306_t disp);
double U64ToDoubleConverter(uint64_t val);
double determineNote(double frequency, char * output_note_string, char * output_octave_string);
void drawGuitarStringIndicator(ssd1306_t* disp, int stringIndex);
void drawOscilloscope(ssd1306_t* disp, float max_freq);
void cumulSamples(void);

int main() {
  // Overclock Pico
  bool overclockingSuccess = true;
  if (!set_sys_clock_khz(150000, true)) {
    set_sys_clock_khz(125000, true);
    overclockingSuccess = false;
  }
  // STDIO
  stdio_init_all();

  printf("configuring pins...\n");
  setup_gpios();
  printf("display init...\n");
  ssd1306_t disp;
  disp.external_vcc = false;
  ssd1306_init( & disp, 128, 64, 0x3C, i2c0);
  if (!overclockingSuccess) {
    printf("overclock failed...\n");
    overclockFail(disp);
    return 0;
  }
  splashscreen(disp);
  // initialize the PDM microphone
  printf("microphone init...\n");
  setup_microphone();
  // Start main UI.
  showMainUI(disp);
  return 0;
}

void on_pdm_samples_ready(void) {
  // callback from library when all the samples in the library
  // internal sample buffer are ready for reading
  samples_read = pdm_microphone_read(sample_buffer, MIC_BUFFER_SIZE);
}

void setup_microphone(void) {
  // set callback that is called when all the samples in the library
  // internal sample buffer are ready for reading
  if (pdm_microphone_init( & config) < 0) {
    printf("PDM microphone initialization failed!\n");
  }
  pdm_microphone_set_samples_ready_handler(on_pdm_samples_ready);
  // start capturing data from the PDM microphone
  if (pdm_microphone_start() < 0) {
    printf("PDM microphone start failed!\n");
  }
}

void setup_gpios(void) {
  i2c_init(i2c0, 400000);
  gpio_set_function(17, GPIO_FUNC_I2C);
  gpio_set_function(16, GPIO_FUNC_I2C);
  gpio_pull_up(17);
  gpio_pull_up(16);
}

void splashscreen(ssd1306_t disp) {
  ssd1306_clear( & disp);
  printf("Showing splash screen!\n");
  ssd1306_bmp_show_image( & disp, splash_screen_image_data, splash_screen_image_size);
  ssd1306_show( & disp);
  sleep_ms(SPLASHSCREEN_DURATION);
}

void overclockFail(ssd1306_t disp) {
  ssd1306_clear( & disp);
  printf("Showing overclock fail screen!\n");
  ssd1306_bmp_show_image( & disp, overclockfail_screen_image_data, overclockfail_screen_image_size);
  ssd1306_show( & disp);
}

double U64ToDoubleConverter(uint64_t val) {
  double convertedValue = 0.0;
  memcpy( & convertedValue, & val, sizeof(convertedValue));
  return convertedValue;
}

double determineNote(double frequency, char * output_note_string, char * output_octave_string) {
  if (frequency < CUTOFF_FREQUENCY) {
    strcpy(output_note_string, "L");
    strcpy(output_octave_string, "-");
    return (0);
  } else {
    double octaves_over_C0 = log2l(frequency / C0_FREQUENCY);
    double semitones_over_C0 = octaves_over_C0 * 12.0;
    int closest_whole_semitones_over_C0 = round(semitones_over_C0);
    char * closestnote = (char * ) malloc(2 * sizeof(char));
    char * octaveString = (char * ) malloc(2 * sizeof(char));
    strcpy(closestnote, notes_in_an_octave[closest_whole_semitones_over_C0 % 12]);
    sprintf(octaveString, "%i", (int)(floor(round(semitones_over_C0) / 12)));
    strcpy(output_note_string, closestnote);
    strcpy(output_octave_string, octaveString);
    free(closestnote); // no memory leaks here 😅...
    free(octaveString); // no memory leaks here 😅...
    return (semitones_over_C0 - closest_whole_semitones_over_C0);
  }
}

void drawGuitarStringIndicator(ssd1306_t* disp, int stringIndex) {
  ssd1306_draw_square(disp, 3 + stringIndex * 5, 35, 3, 3); // 3, 35
}

void drawOscilloscope(ssd1306_t* disp, float max_freq){
  int samples_to_read = OSCILLOSCOPE_SAMPLES;
  if (max_freq != 0){
  samples_to_read = round(2/max_freq*MIC_SAMPLERATE);
  }
  if (samples_to_read<=MIC_BUFFER_SIZE*CUMUL_BUFFER_SIZE){
  float sample_offset = (float)samples_to_read/OSCILLOSCOPE_SAMPLES;
  int16_t max_value = 1;
  for (int i = 0; i < OSCILLOSCOPE_SAMPLES; ++i) {
      if (abs(sample_buffer_cumul[(int)round(sample_offset*i)+MIC_BUFFER_SIZE*CUMUL_BUFFER_SIZE-samples_to_read]) > max_value) {
        max_value=abs(sample_buffer_cumul[(int)round(sample_offset*i)+MIC_BUFFER_SIZE*CUMUL_BUFFER_SIZE-samples_to_read]);
      }
    }
  for (int i = 0; i < OSCILLOSCOPE_SAMPLES; ++i) {
      ssd1306_draw_pixel(disp,125-i,35+round(((float)sample_buffer_cumul[(int)round(sample_offset*i)])/((float)max_value)*OSCILLOSCOPE_GAIN));
    }
  }
  }

void displayTunerResults(ssd1306_t disp, char * output_note_letter, char * output_note_string, char * output_octave_string, char * output_cents_offset_string, double note_semitones_offset, float max_freq) {
  // Draw UI background skin
  ssd1306_bmp_show_image( & disp, main_ui_image_data, main_ui_image_size);
  // Display closest note
  ssd1306_draw_string( & disp, 59, 24, 2, output_note_letter); // (128-10)/2, (64-16)/2
  ssd1306_draw_string( & disp, 69, 20, 1, & (output_note_string[1])); // (128-10)/2+10+4, (64-16)/2-4
  ssd1306_draw_string( & disp, 69, 36, 1, output_octave_string); // (128-10)/2+10, (64-16)/2+12
  // Draw the offset bar
  if (note_semitones_offset < 0) {
    sprintf(output_cents_offset_string, "%dc", (int)(round(note_semitones_offset * 100)));
    ssd1306_draw_string( & disp, 28, 48, 1, output_cents_offset_string); // 128/2-4*5-16, 64-2-6-8
    ssd1306_draw_square( & disp, (int)(round(64 + (note_semitones_offset * 100 * SEMITONE_OFFSET_SENSITIVITY))), 56, (int)(round(fabs(note_semitones_offset * 100 * SEMITONE_OFFSET_SENSITIVITY))), 6); // 128/2, 64-2-6
  } else {
    sprintf(output_cents_offset_string, "+%dc", (int)(round(note_semitones_offset * 100)));
    ssd1306_draw_string( & disp, 80, 48, 1, output_cents_offset_string); // 128/2+16, 64-2-6-8
    ssd1306_draw_square( & disp, 64, 56, (int)(round(fabs(note_semitones_offset * 100 * SEMITONE_OFFSET_SENSITIVITY))), 6); // 128/2, 64-2-6
  }
  if (strcmp(output_octave_string, "2") == 0) {
    if (strcmp(output_note_string, "E") == 0) {
      drawGuitarStringIndicator(&disp, 0);
    }
    if (strcmp(output_note_string, "A") == 0) {
      drawGuitarStringIndicator(&disp, 1);
    }
  }
  if (strcmp(output_octave_string, "3") == 0) {
    if (strcmp(output_note_string, "D") == 0) {
      drawGuitarStringIndicator(&disp, 2);
    }
    if (strcmp(output_note_string, "G") == 0) {
      drawGuitarStringIndicator(&disp, 3);
    }
    if (strcmp(output_note_string, "B") == 0) {
      drawGuitarStringIndicator(&disp, 4);
    }
  }
  if (strcmp(output_octave_string, "4") == 0) {
    if (strcmp(output_note_string, "E") == 0) {
      drawGuitarStringIndicator(&disp, 5);
    }
  }
  drawOscilloscope(&disp,max_freq);
  // Display result
  ssd1306_show( & disp);
  ssd1306_clear( & disp);
}

double signnum_c(double x) {
  if (x > 0.0) return 1.0;
  if (x < 0.0) return -1.0;
  return x;
}

void cumulSamples(){
  multicore_fifo_push_blocking(FLAG_VALUE);
  uint32_t g = multicore_fifo_pop_blocking();
  if (g != FLAG_VALUE){
        printf("Hmm, that's not right on core 1!\n");
  } else {
        printf("Its all gone well on core 1!");
  }
  for(;;){
  while (samples_read == 0) {}
  int sample_count = samples_read;
  memcpy (&sample_buffer_cumul[0],&sample_buffer_cumul[MIC_BUFFER_SIZE],MIC_BUFFER_SIZE*sizeof(int16_t)*(CUMUL_BUFFER_SIZE-1));
  memcpy (&sample_buffer_cumul[MIC_BUFFER_SIZE*(CUMUL_BUFFER_SIZE-1)],&sample_buffer[0],MIC_BUFFER_SIZE*sizeof(int16_t));
  printf("blocking core 1!");
  multicore_fifo_push_blocking(FLAG_VALUE);
    printf("core 1 unblocked!");
  }
}

void showMainUI(ssd1306_t disp) {
  // FFT setup start.
  // calculate frequencies of each bin
  float f_max = MIC_SAMPLERATE;
  float f_res = f_max / (MIC_BUFFER_SIZE*CUMUL_BUFFER_SIZE);
  for (int i = 0; i < (MIC_BUFFER_SIZE*CUMUL_BUFFER_SIZE); i++) {
    freqs[i] = f_res * i;
  }
  kiss_fft_scalar fft_in[(MIC_BUFFER_SIZE*CUMUL_BUFFER_SIZE)]; // kiss_fft_scalar is a float
  kiss_fft_cpx fft_out[(MIC_BUFFER_SIZE*CUMUL_BUFFER_SIZE)];
  kiss_fftr_cfg cfg = kiss_fftr_alloc((MIC_BUFFER_SIZE*CUMUL_BUFFER_SIZE), false, 0, 0);
  // FFT setup end.
  ssd1306_clear( & disp);
  char * old_output_note_string = (char * ) malloc(6 * sizeof(char));
  char * old_output_octave_string = (char * ) malloc(6 * sizeof(char));
  double old_note_semitones_offset = 0;
  bool is_this_the_first_output_note = true;
  // Allocate memory for temporary variables
  char * output_note_letter = (char * ) malloc(1 * sizeof(char));
  char * output_cents_offset_string = (char * ) malloc(4 * sizeof(char));
  char * output_note_string = (char * ) malloc(6 * sizeof(char));
  char * output_octave_string = (char * ) malloc(6 * sizeof(char));
  double note_semitones_offset = 0.0;
  // Boot animation
  if (SHOW_BOOT_ANIMATION) {
    double boot_animation_position = -0.5;
    double boot_velocity = 0.0;
    for (int i = 0; i < BOOT_ANIMATION_FRAMES; ++i) {
      displayTunerResults(disp, "L+", "L", "0", output_cents_offset_string, boot_animation_position, 0);
      boot_velocity += -signnum_c(boot_animation_position) / (boot_animation_position * boot_animation_position + 0.1) / 2000.0;
      boot_animation_position += boot_velocity;
    }
  }
  multicore_launch_core1(cumulSamples);
  uint32_t g = multicore_fifo_pop_blocking();
 
    if (g != FLAG_VALUE){
        printf("Hmm, that's not right on core 0!\n");
    }
    else {
        multicore_fifo_push_blocking(FLAG_VALUE);
        printf("It's all gone well on core 0!");
    }
  for (;;) {
    printf("blocking core 0!");
    multicore_fifo_pop_blocking();
    printf("core 0 unblocked!");
    // FFT calculations (Dear future self, it's 4AM as I'm writing this. Please forgive me for any bugs, memory leaks or thermonuclear war (see what I did there?))
    // fill fourier transform input while subtracting DC component
    uint64_t sum = 0;
    for (int i = 0; i < (MIC_BUFFER_SIZE*CUMUL_BUFFER_SIZE); i++) {
      sum += sample_buffer_cumul[i] * MIC_GAIN;
    }
    float avg = ((float)(sum)) / ((double) (MIC_BUFFER_SIZE*CUMUL_BUFFER_SIZE));

    for (int i = 0; i < (MIC_BUFFER_SIZE*CUMUL_BUFFER_SIZE); i++) {
      fft_in[i] = sample_buffer_cumul[i] * MIC_GAIN - avg;
    }
    // compute fast fourier transform
    kiss_fftr(cfg, fft_in, fft_out);

    // compute power and calculate max freq component
    float max_power = 0;
    int max_idx = 0;
    // any frequency bin over MIC_BUFFER_SIZE/2 is aliased (nyquist sampling theorum)
    for (int i = 0; i < (MIC_BUFFER_SIZE*CUMUL_BUFFER_SIZE) / 2; i++) {
      float power = fft_out[i].r * fft_out[i].r + fft_out[i].i * fft_out[i].i;
      if (power > max_power) {
        max_power = power;
        max_idx = i;
      }
    }

    float max_freq = freqs[max_idx];
    printf("Greatest Frequency Component: %0.1f Hz\n", max_freq);
    // Determine played note and offset
    note_semitones_offset = determineNote(max_freq, output_note_string, output_octave_string);
    if (is_this_the_first_output_note) {
      is_this_the_first_output_note = false;
      sprintf(old_output_note_string, "%s", output_note_string);
      sprintf(old_output_octave_string, "%s", output_octave_string);
      old_note_semitones_offset = note_semitones_offset;
    } else {
      if (strcmp(output_note_string, "L") == 0) {
        sprintf(output_note_string, "%s", old_output_note_string);
        sprintf(output_octave_string, "%s", old_output_octave_string);
        note_semitones_offset = old_note_semitones_offset;
      } else {
        sprintf(old_output_note_string, "%s", output_note_string);
        sprintf(old_output_octave_string, "%s", output_octave_string);
        old_note_semitones_offset = note_semitones_offset;
      }
    }
    sprintf(output_note_letter, "%c", output_note_string[0]);
    displayTunerResults(disp, output_note_letter, output_note_string, output_octave_string, output_cents_offset_string, note_semitones_offset, max_freq);
  }
}

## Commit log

2022-11-19 Alpha 1.0.9
    [2.blend]
2022-11-20 Alpha 1.0.9 - New Body
    [asanoha.scad, bottom-v2.scad, bottom-v2.stl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]
2022-11-20 Alpha 1.0.9 - New Body v2
    [top-v2.scad, top-v2.stl]
2024-10-31 feat: add CAD drawings
    [CLIP_CR2032_RS_PRO_2378331.step, M2 x 0.4mm Thread 16mm LONG SOCKET HEAD CAP SCREW.STEP, M2 x 0.4mm Thread HEX NUT.STEP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]
